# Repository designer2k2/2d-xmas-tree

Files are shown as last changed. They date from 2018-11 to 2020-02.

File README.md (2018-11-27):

# 2d-xmas-Tree
a DIY flat christmas decoration with a ATtiny25, 20 led´s and a coin cell battery 

## DIY 2D christmas decoration

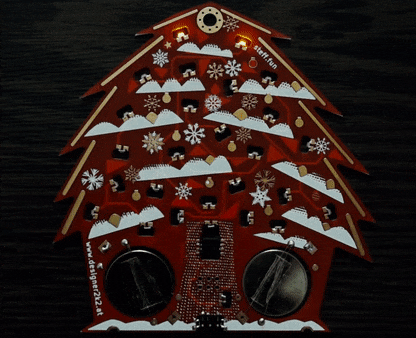
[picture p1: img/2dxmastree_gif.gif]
Image from the 2D xmas tree


This is a only 2 dimensional pcb with all the components embedded into the 1,6mm thick pcb itself.
The components are placed with the help of castellation into the pcb. 

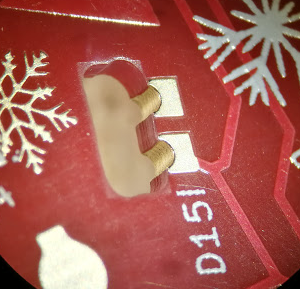
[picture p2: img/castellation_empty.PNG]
Castellation empty
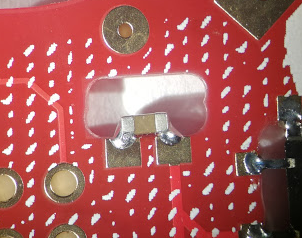
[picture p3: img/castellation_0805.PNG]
Castellation with component
 

All files including the Code for the ATtiny and the KiCad Files for the PCB are here, OSHW!

## create your own patterns

a helper to get the patterns graphically made: https://designer2k2.github.io/2d-xmas-tree/

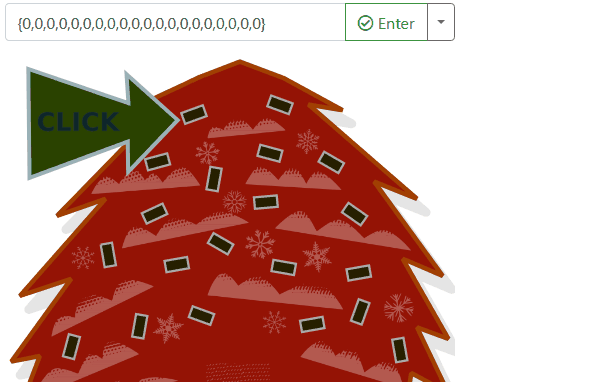
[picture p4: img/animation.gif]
GUI demonstration


## make your own

see the wiki page on how to make it: https://github.com/designer2k2/2d-xmas-tree/wiki

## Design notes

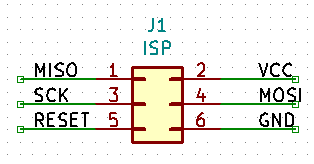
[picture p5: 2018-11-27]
img/isp_pinout.PNG

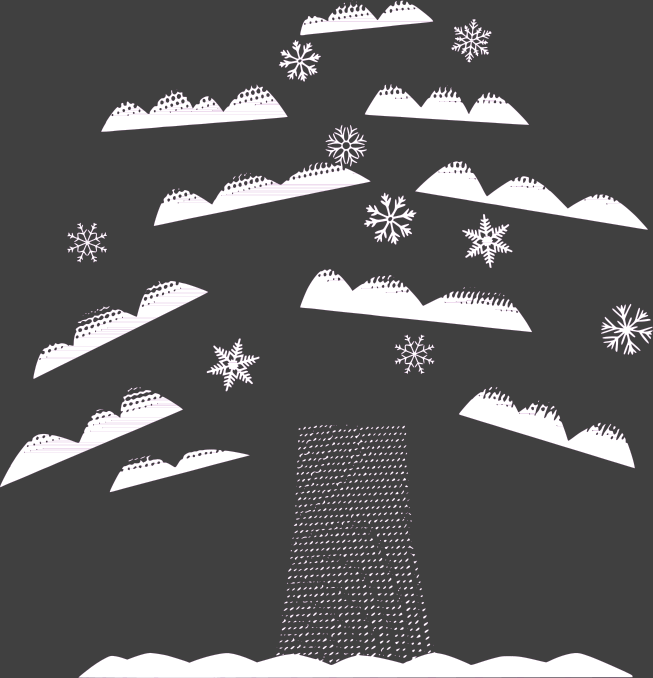
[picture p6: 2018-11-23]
docs/snow.png

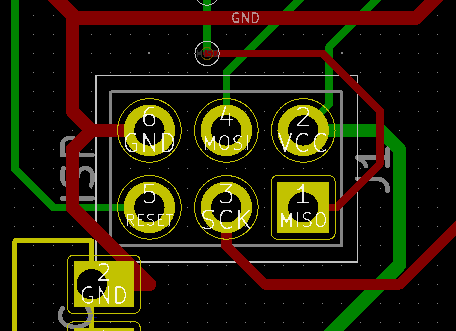
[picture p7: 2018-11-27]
img/isp_inpcb.PNG

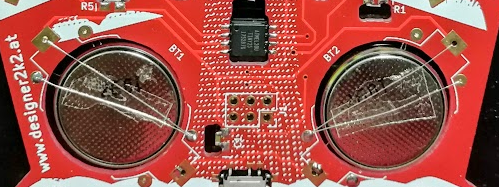
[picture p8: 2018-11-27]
img/batterymounted.PNG

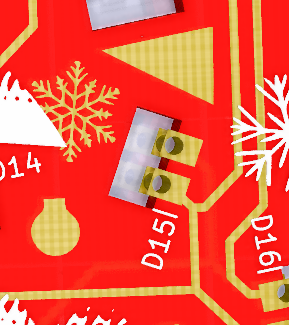
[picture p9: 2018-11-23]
img/castellation_kicad.PNG

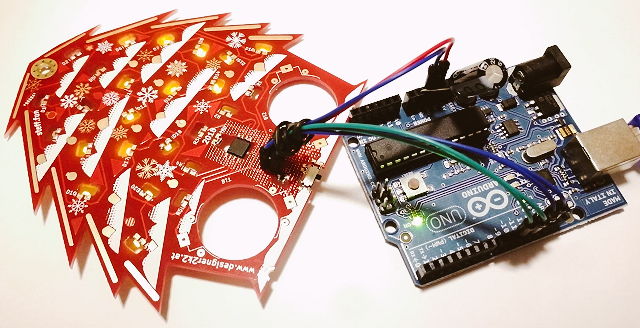
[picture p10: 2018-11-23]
img/2d_xmas_tree_programming.jpg

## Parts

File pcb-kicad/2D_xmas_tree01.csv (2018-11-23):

Reference Type | Quantity | Reference | Value | Footprint | RS | Digikey
BT | 2 | BT1;BT2; | Battery_Cell | 2016
C | 1 | C1; | C | 0805
D | 20 | D1;D2;D3;D4;D5;D6;D7;D8;D9;D10;D11;D12;D13;D14;D15;D16;D17;D18;D19;D20; | LED | 0805
J | 1 | J1; | ISP
R | 5 | R1;R2;R3;R4;R5; | R | 0805
R | 1 | R6; | 10k | 0805
SW | 1 | SW1; | SW_SPDT | PCM12SMTR
U | 1 | U1; | ATTINY25-20SU | SOIC8

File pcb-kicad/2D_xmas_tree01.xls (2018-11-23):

Reference Type | Quantity | Reference | Value | Footprint | RS | Digikey | Price | Price x Qty
BT | 2 | BT1;BT2; | Battery_Cell | 2016 | - | - |  | 0.00 €
C | 1 | C1; | 22µF | 0805 | 790-0682 | 1276-6786-1-ND | 0.34 € | 0.34 €
D | 20 | D1;D2;D3;D4;D5;D6;D7;D8;D9;D10;D11;D12;D13;D14;D15;D16;D17;D18;D19;D20; | LED | 0805 | 176-6117 | 516-1431-1-ND | 0.52 € | 10.40 €
J | 1 | J1; | ISP |  | - | - |  | 0.00 €
R | 5 | R1;R2;R3;R4;R5; | 75 | 0805 |  | RR12Q75DCT-ND | 0.10 € | 0.50 €
R | 1 | R6; | 10k | 0805 | 125-1189 | RR12P10.0KDCT-ND | 0.10 € | 0.10 €
SW | 1 | SW1; | SW_SPDT | PCM12SMTR | 793-1721 | 401-2016-1-ND | 0.80 € | 0.80 €
U | 1 | U1; | ATTINY25-20SU | SOIC8 | 133-1611 | ATTINY25-20SU-ND | 0.93 € | 0.93 €
 |  |  |  |  |  |  |  | 13.07 €

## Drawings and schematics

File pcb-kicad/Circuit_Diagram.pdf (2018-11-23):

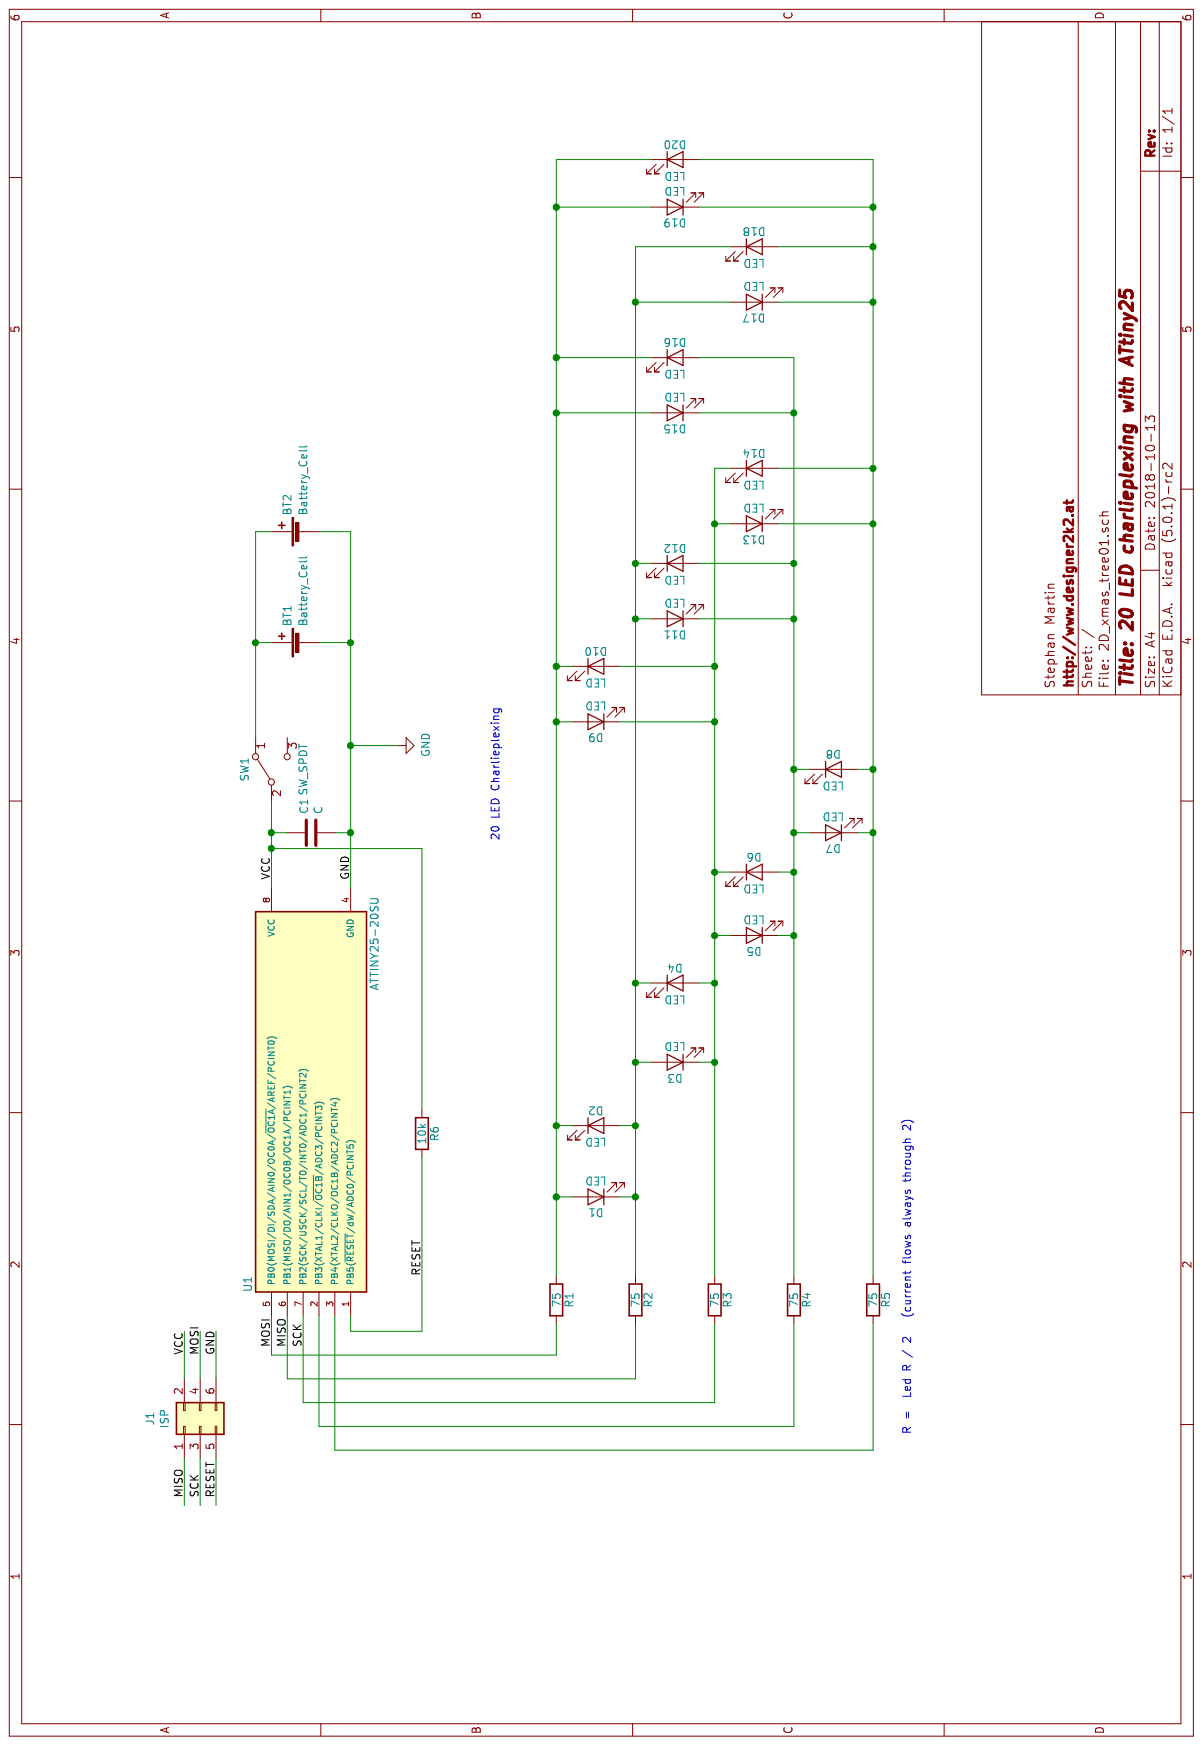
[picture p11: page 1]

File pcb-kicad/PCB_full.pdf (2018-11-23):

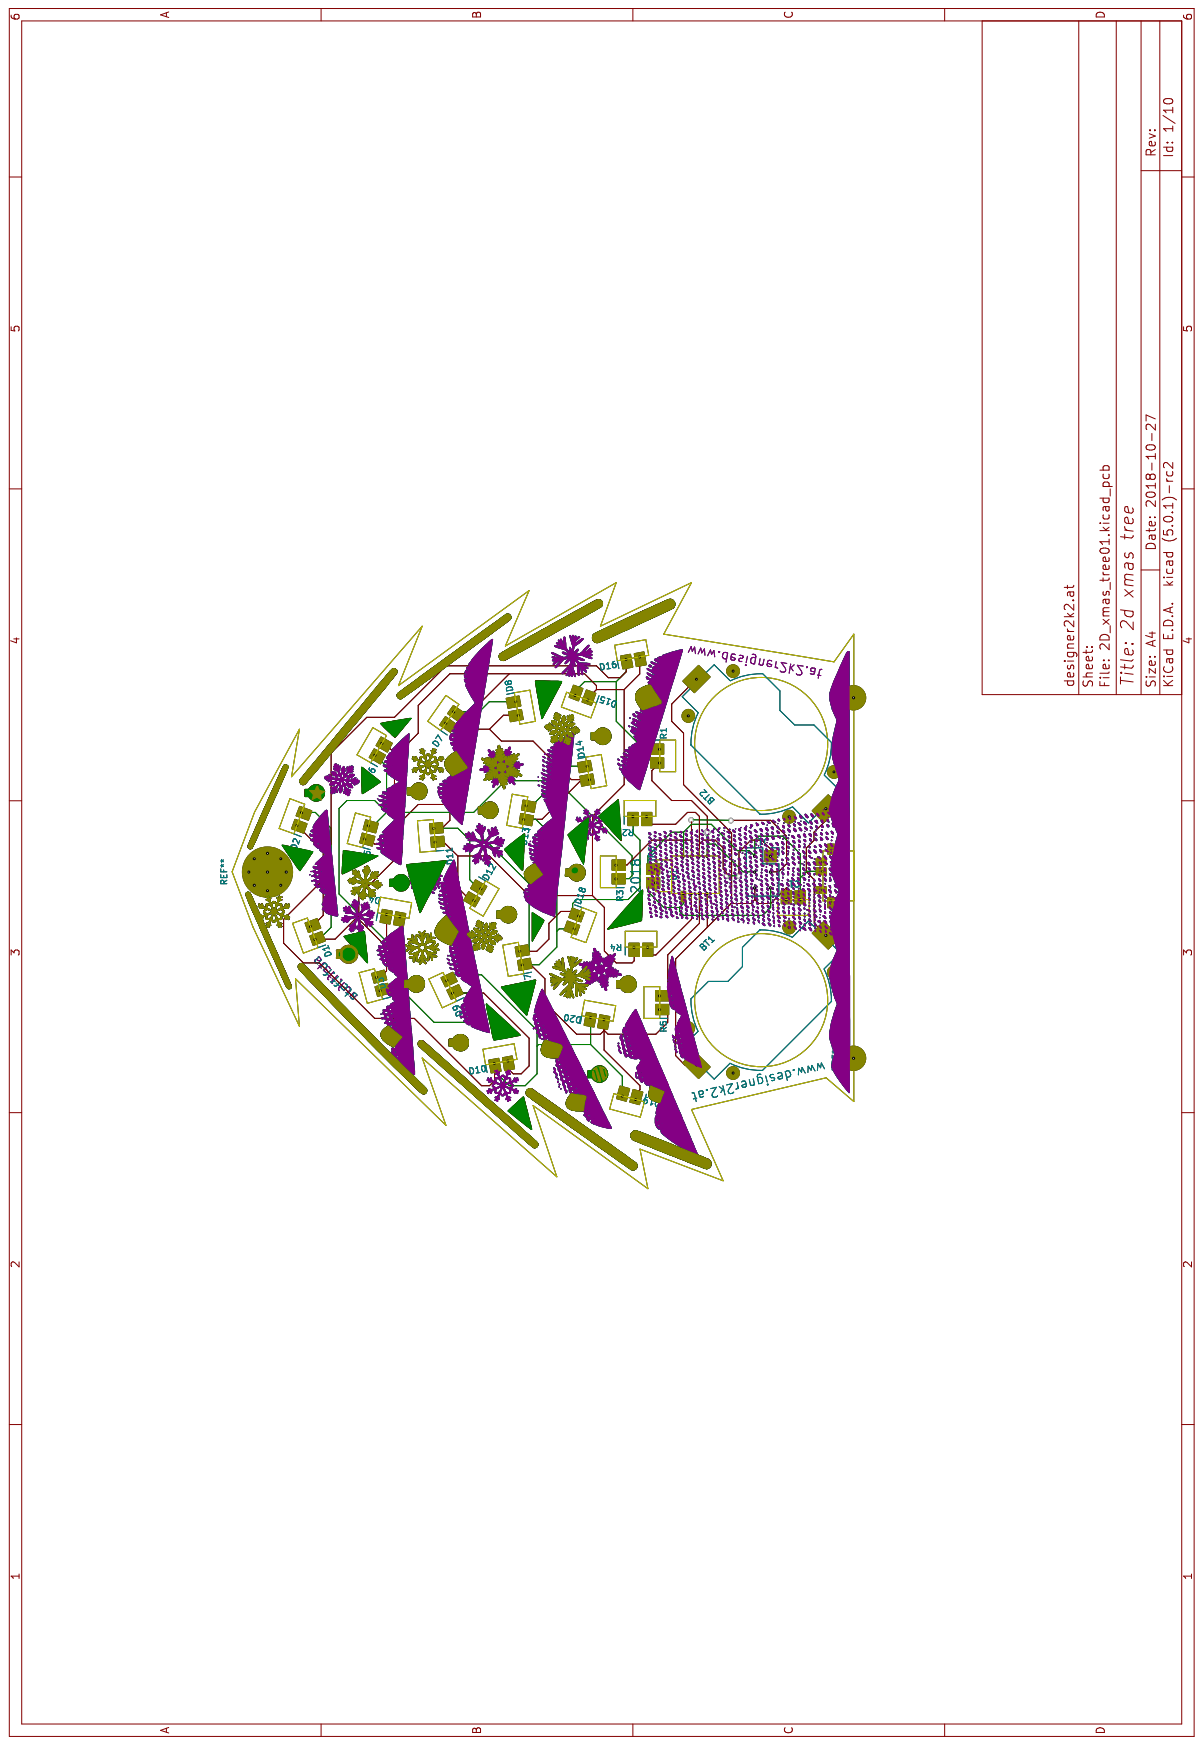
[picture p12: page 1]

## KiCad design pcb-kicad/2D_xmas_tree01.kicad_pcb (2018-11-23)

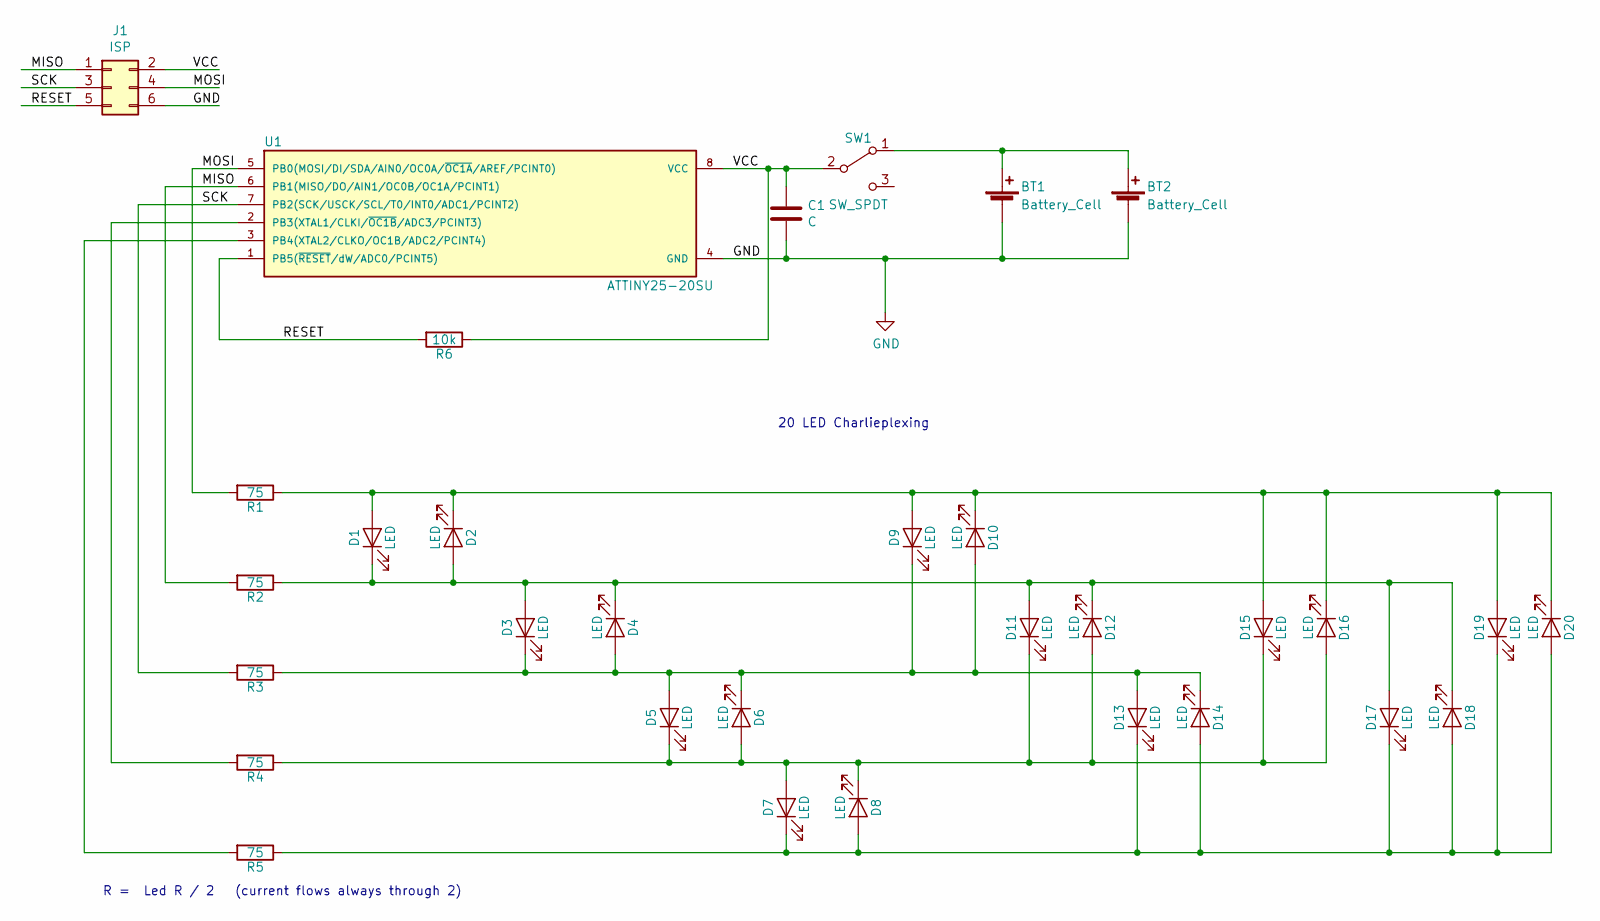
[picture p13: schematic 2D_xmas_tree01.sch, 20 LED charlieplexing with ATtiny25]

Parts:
BT1, BT2: Battery_Cell; Keystone_1058_1x2032-CoinCell_Inside
C1: C; 0805_Internal_Castellation
D1, D2, D3, D4, D5, D6, D7, D8, D9, D10, D11, D12, D13, D14, D15, D16, D17, D18, D19, D20: LED; 0805_Internal_Castellation
J1: ISP; Socket_Strip_Straight_2x03_Pitch2.54mm
R1, R2, R3, R4, R5: 75; 0805_Internal_Castellation
R6: 10k; 0805_Internal_Castellation
SW1: SW_SPDT; PCM12SMTR_inside
U1: ATTINY25-20SU; SOIC-8_Inside

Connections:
/MISO: J1.1, R2.2, U1.6 (PB1(MISO/DO/AIN1/OC0B/OC1A/PCINT1))
/MOSI: J1.4, R1.2, U1.5 (PB0(MOSI/DI/SDA/AIN0/OC0A/~OC1A~/AREF/P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)
/RESET: J1.5, R6.2, U1.1 (PB5(~RESET~/dW/ADC0/PCINT5))
/SCK: J1.3, R3.2, U1.7 (PB2(SCK/USCK/SCL/T0/INT0/ADC1/PCINT2))
/VCC: C1.1, J1.2, R6.1, SW1.2 (B), U1.8 (VCC)
GND: BT1.2 (-), BT2.2 (-), C1.2, J1.6, U1.4 (GND)
unnamed: BT1.1 (+), BT2.1 (+), SW1.1 (A)
unnamed: D1.1 (K), D2.2 (A), D3.2 (A), D4.1 (K), D11.2 (A), D12.1 (K), D17.2 (A), D18.1 (K), R2.1
unnamed: D1.2 (A), D2.1 (K), D9.2 (A), D10.1 (K), D15.2 (A), D16.1 (K), D19.2 (A), D20.1 (K), R1.1
unnamed: D3.1 (K), D4.2 (A), D5.2 (A), D6.1 (K), D9.1 (K), D10.2 (A), D13.2 (A), D14.1 (K), R3.1
unnamed: D5.1 (K), D6.2 (A), D7.2 (A), D8.1 (K), D11.1 (K), D12.2 (A), D15.1 (K), D16.2 (A), R4.1
unnamed: D7.1 (K), D8.2 (A), D13.1 (K), D14.2 (A), D17.1 (K), D18.2 (A), D19.1 (K), D20.2 (A), R5.1
unnamed: R4.2, U1.2 (PB3(XTAL1/CLKI/~OC1B~/ADC3/PCINT3))
unnamed: R5.2, U1.3 (PB4(XTAL2/CLKO/OC1B/ADC2/PCINT4))

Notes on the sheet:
R = Led R / 2 (current flows always through 2)
20 LED Charlieplexing

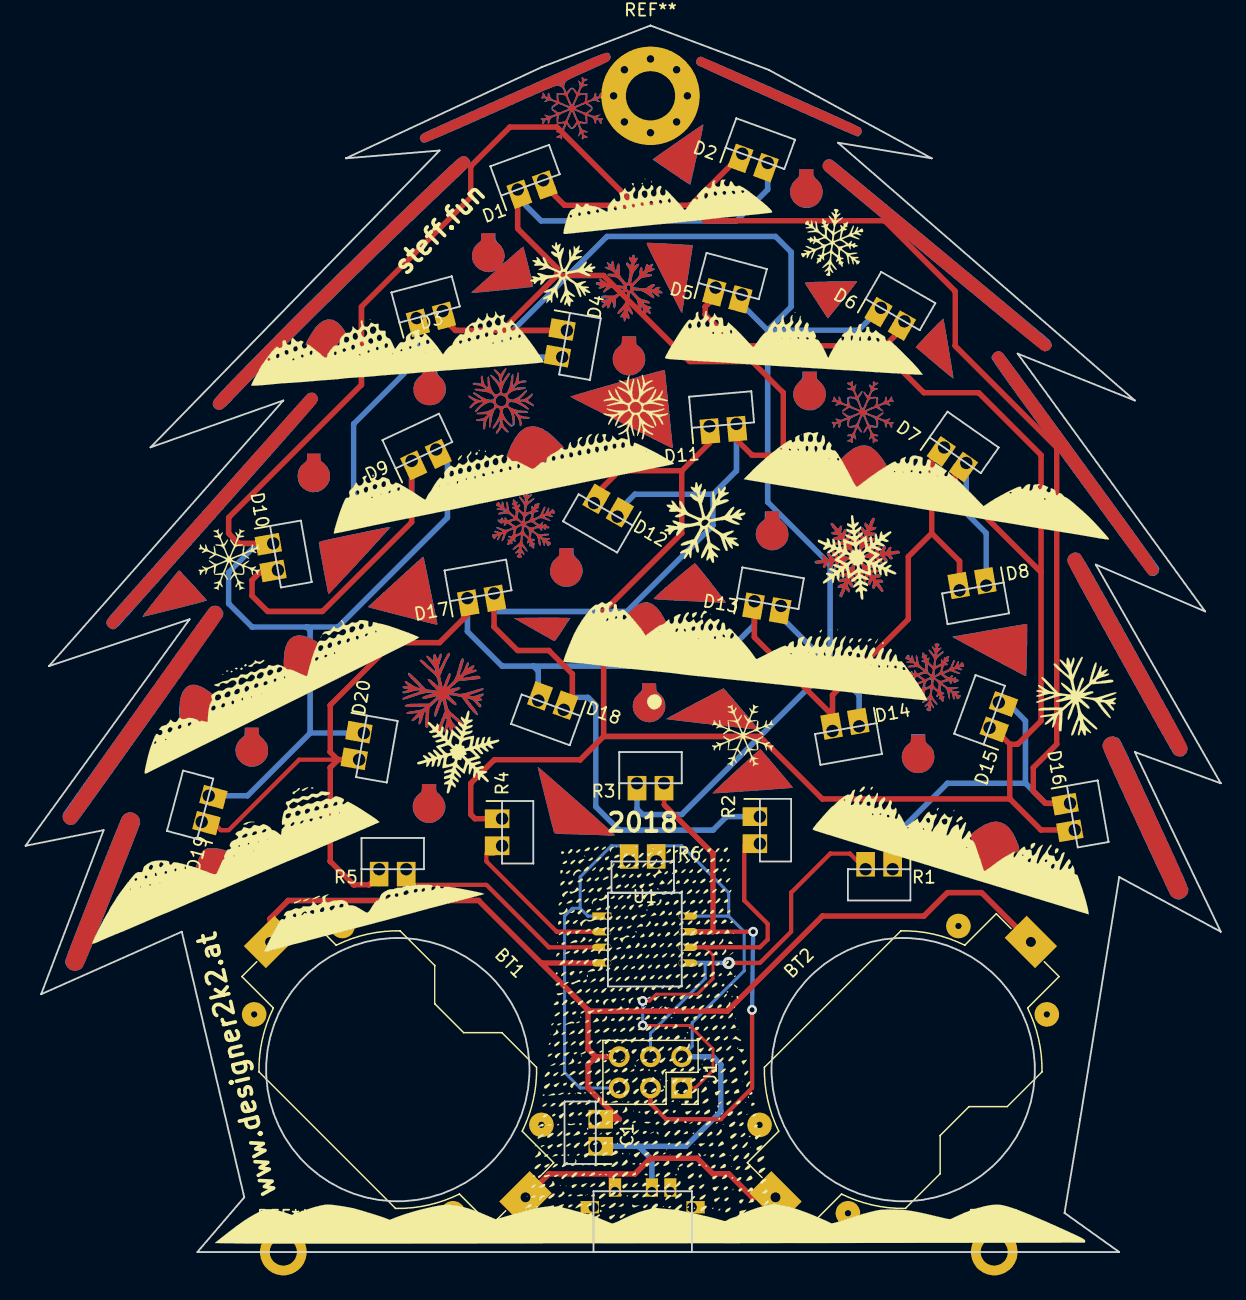
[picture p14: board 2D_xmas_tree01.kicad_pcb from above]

Board: 2 copper layers, 97.2 x 99.7 mm, 32 parts (0 on the bottom side), 14 nets.

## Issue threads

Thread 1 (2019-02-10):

Battery holder

TAGood827, 2019-02-10:
Thanks for sharing this project! Just wondering if there was a specific battery holder used in the design? I'm thinking about designing a rear stand sort of thing for a couple to be able to sit on a table.

designer2k2, 2019-02-10:
Hello,
the Battery holder has to be made with thin wire: https://github.com/designer2k2/2d-xmas-tree/wiki#Battery

Construction is in the video from 5:12 onwards: https://www.youtube.com/watch?v=K6z7--RqQHQ

The lower side from the PCB has 2 exposed vias, there you can solder in a piece of thick copper wire to make a simple stand:
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

Closed 2019-03-07.

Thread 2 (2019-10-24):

Should we update year on the front side?

kasedy, 2019-10-24:
There is 2018 label on the front side. Should we update it to 2020 or make it smaller and move to a side as a designing/manufacturing year?

designer2k2, 2019-10-25:
Hello,
you can modify it to your liking, for me it will stay as my 2018 xmas project.

There is my 2016 digistump tree: https://github.com/designer2k2/xmas-tree
And the 2017 raspberry pi tree: https://www.designer2k2.at/en/mods/elektronik/134-overpowered-raspberry-pi-xmas-led-tree

Closed 2019-10-25.

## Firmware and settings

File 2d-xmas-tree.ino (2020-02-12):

/* 
 2D XMAS Tree Code
 charlieplexing christmas decoration
 5 Pins with 20 LED´s

 ATtiny25, 1MHZ Internal Clock, no BOD


 Hosted on Github: 
 
 https://github.com/designer2k2/2d-xmas-tree

 Made by:
 
 https://www.designer2k2.at

  MIT License
  
  Copyright (c) [2018] [Stephan Martin]
  
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
  THE SOFTWARE IS PROVIDED "AS IS", WITHOUT WARRANTY OF ANY KIND, EXPRESS OR
  IMPLIED, INCLUDING BUT NOT LIMITED TO THE WARRANTIES OF MERCHANTABILITY,
  FITNESS FOR A PARTICULAR PURPOSE AND NONINFRINGEMENT. IN NO EVENT SHALL THE
  AUTHORS OR COPYRIGHT HOLDERS BE LIABLE FOR ANY CLAIM, DAMAGES OR OTHER
  LIABILITY, WHETHER IN AN ACTION OF CONTRACT, TORT OR OTHERWISE, ARISING FROM,
  OUT OF OR IN CONNECTION WITH THE SOFTWARE OR THE USE OR OTHER DEALINGS IN THE
  SOFTWARE.
*/

#include <avr/pgmspace.h>

//Enter the light pattern here:
//use the online generator: https://designer2k2.github.io/2d-xmas-tree/
//dont forget to update the number of rows if changed

static const bool state_table[14][21] PROGMEM = {
                 {1,1,0,0,0,0,0,0,0,0,0,0,0,0,0,0,0,0,0,0},
                 {0,0,1,1,1,1,0,0,0,0,0,0,0,0,0,0,0,0,0,0},
                 {0,0,0,0,0,0,1,0,1,0,1,1,0,0,0,0,0,0,0,0},
                 {0,0,0,0,0,0,0,1,0,1,0,0,1,0,0,0,1,0,0,0},
                 {0,0,0,0,0,0,0,0,0,0,0,0,0,1,1,1,0,1,1,1},
                 {0,0,0,0,0,0,0,0,0,0,0,0,0,0,0,0,0,0,1,0},
                 {0,0,1,0,0,0,0,0,1,0,0,0,0,0,0,0,1,1,0,0},
                 {1,0,0,1,0,0,0,0,0,0,0,1,0,0,0,0,0,0,0,0},
                 {0,0,0,0,0,1,1,1,0,0,0,0,0,1,0,0,0,0,0,0},
                 {0,0,0,0,0,0,0,0,0,0,0,0,0,0,1,1,0,0,0,0},
                 {0,1,0,0,1,0,0,0,0,0,1,0,1,0,0,0,0,0,0,0},
                 {0,0,1,0,0,0,0,0,1,0,0,0,0,0,0,0,1,1,0,0},
                 {0,0,0,0,0,0,0,0,0,1,0,0,0,0,0,0,0,0,0,1},
                 {0,0,0,0,0,0,0,0,0,0,0,0,0,0,0,0,0,0,1,0}
};
#define NumRows 14  //default is 14 (and about the space limit)

//the delay in ms between the patterns:
#define pattern_delay 500

//intro time (how long the random change happens) in ms:
#define introtime 10000

//time a led is on in us:
//increase this to have the leds "flicker"
#define ondelay 1000


//-------------------------------------------------------------------------------------
//below is the code to make this all happen, modify to make even fancier effects as you wish!

//This holds the pin configuration to make the 20 led charlieplexing,
//only 1 in PROGMEM, as the FLASH is full, but both are too large for RAM.
int pinvcc[] = {0,1,1,2,2,3,3,4,0,2,1,3,2,4,0,3,1,4,0,4};
const PROGMEM int pingnd[] = {1,0,2,1,3,2,4,3,2,0,3,1,4,2,3,0,4,1,4,0};

//placeholder for all current leds:
bool ledstate[] = {0,0,0,0,0,0,0,0,0,0,0,0,0,0,0,0,0,0,0,0}; 

unsigned long lasttime, lastintrotime;

int iState;

void setup() {
  //Need to define the Pins as input (defaults)
  tristate();

  // disable ADC (power saving):
  ADCSRA = 0;  

  //init the time with 0
  lasttime = 0;
  lastintrotime = introtime;

  //start with the first pattern
  iState = 0;

}

void loop(){
  // put your main code here, to run repeatedly:

  // every 100ms change a random led to a random state
  if(millis()<lastintrotime){
    if(millis()>(lasttime+10)){
      int ledtoset = random(20);
      bool ledbool = random(2);
      ledstate[ledtoset] = ledbool;
      lasttime = millis();
    }
  }else{
  //loop trough the states in state_table  

    if(millis()>(lasttime+pattern_delay)){
      for (int i=0; i<20; i++) {
        int state = pgm_read_word(&state_table[iState][i]);

        //PROGMEM with bool gives sometimes strange results, this fixes it:
        if (state==256){
          state = 0;
        }
        
        ledstate[i] = state;
      }
      iState = iState + 1;
      if(iState>=NumRows){
        iState = 0;
        lastintrotime = millis() + introtime;
      }
      lasttime = millis();
    }
  }

  showleds(); 
  
}

//-------------------------------------------------------------------------------------

void showleds(){
  // this cycles trough all the leds in the array and show them.
  
  for (int i=0; i<20; i++) {
   bool state = ledstate[i];
   showled(i,state);
  }
  
}

void showled(int led, bool state){
  //this outputs the led state

  if(state==true){
    //Lookup the pin for high and low:
    int pvcc = pinvcc[led];
    int pgnd = pgm_read_word(&pingnd[led]);

    //set the pinmode for it:
    pinMode(pvcc,OUTPUT);
    pinMode(pgnd,OUTPUT);

    //write the status:
    digitalWrite(pvcc,HIGH);
    digitalWrite(pgnd,LOW);

    //wait a short time to let the LED shine
    delayMicroseconds(ondelay);
    
    //ensure its all turned off properly for the next state
    tristate();
  }
 
}

void tristate(){
  //This tristates all pins
  for (int i=0; i<5; i++) {
   pinMode(i,INPUT);   //Input state
   digitalWrite(i,LOW);//ensure pullups are off.
  }
}

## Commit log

2018-11-23 Initial fill
    with ATtiny Code and KiCad PCB files
    [2D_xmas_tree01-B.Cu.gbr, 2D_xmas_tree01-B.Mask.gbr, 2D_xmas_tree01-B.Paste.gbr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]
2020-11-08 Added interactive BOM
    Interactive BOM with the InteractiveHtmlBom KiCad Plugin: https://github.com/openscopeproject/InteractiveHtmlBom
2020-11-10 Remove non place Parts from Interactive BOM
    Remove non place Parts from Interactive BOM
    Battery holder
    ISP Socket
